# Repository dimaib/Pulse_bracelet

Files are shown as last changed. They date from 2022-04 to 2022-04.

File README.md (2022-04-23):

# Oxemetry and pulsometry
## Description
This system allows you to distribute people between warehouse equipment and give permission to control certain types of machines. It also allows you to take into account the working hours of employees and conduct convenient analytics according to these hours.
## System Composition
- Wrist bracelet
	>The printed circuit board and circuit diagram of the device are created in [KiCad](https://www.kicad.org) 
	Firmware created in Keil uVision for ARM in C languages
- Server that receives data from devices and adds this data to the database
	>The server part was created in Visual Studio C ++, as a console application
	MySQL was used as the database. And MySQL Workbench for administration

## Main view PCB
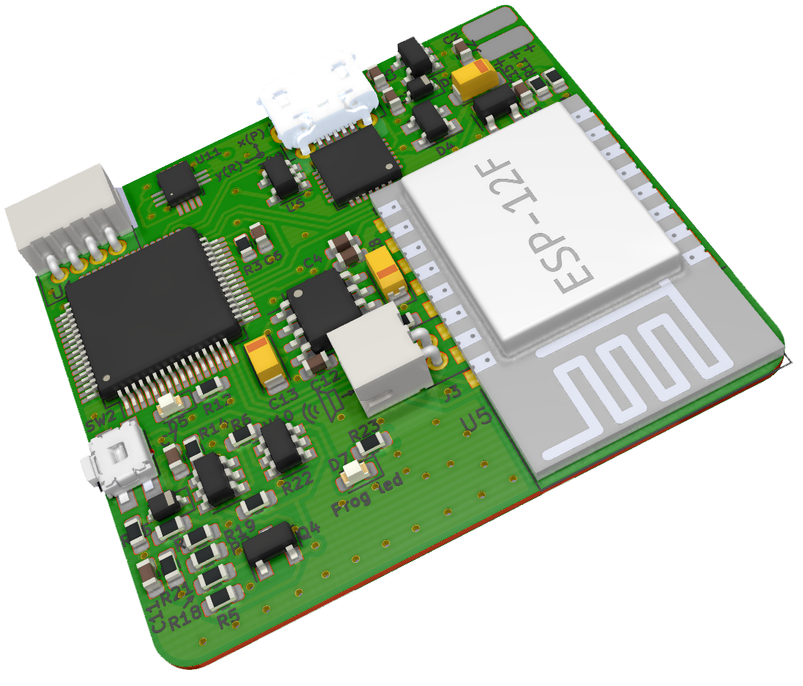
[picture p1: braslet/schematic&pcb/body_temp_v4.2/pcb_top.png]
PCB top

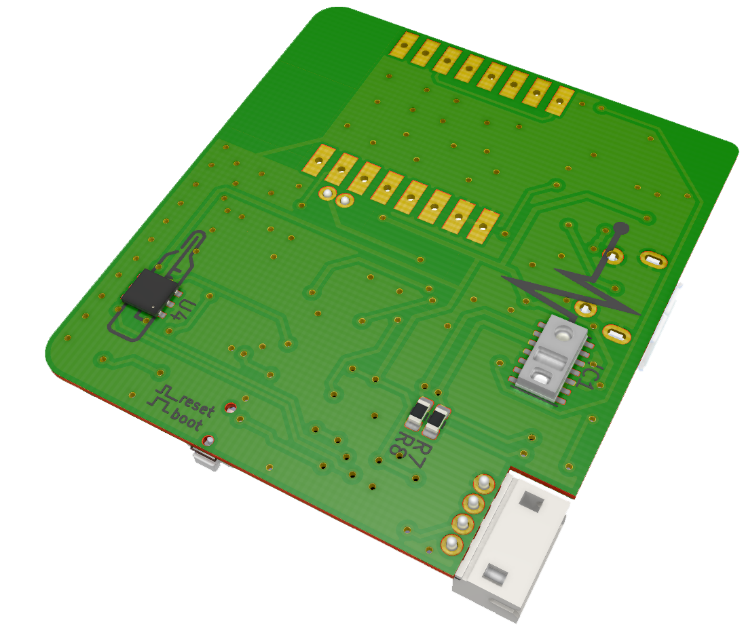
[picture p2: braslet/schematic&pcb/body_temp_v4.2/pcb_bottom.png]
PCB bottom


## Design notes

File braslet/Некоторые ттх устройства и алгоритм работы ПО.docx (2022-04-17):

Алгоритм работы ПО

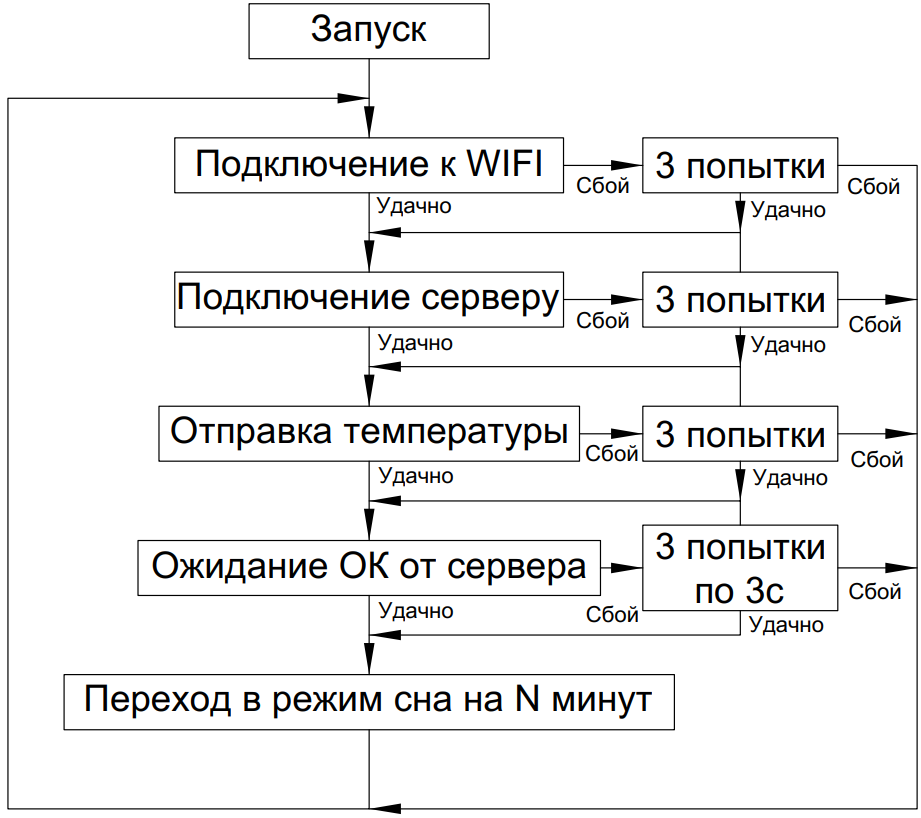
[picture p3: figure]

После запуска устройства происходит инициализация модуля WIFI и попытка подключения к точке доступа, если попытка не удалась, то устройство делает ещё 3 попытки, если они неудачны, то устройство уходит в сон на некоторое время. Если подключение прошло удачно, то устройство создаёт соединение с сервером по протоколу TCP\IP. Если с сервером не удалось соединиться 3 раза подряд, то программа переходит в режим сна. Если удалось создать соединение с сервером, устройство считывает 5 показаний датчика температуры и вычисляет из них среднее значение, после чего отправляет пакет данных на сервер и в течении 3 секунд ожидает ответа. Если ответа не последовало, то происходит ещё 3 попытки отправки пакета, если они не удачны, то устройство переходит в сон. Если попытка отправки пакета была удачной, то устройство переходит в сон.

Пакет отправки данных на сервер выглядит так:

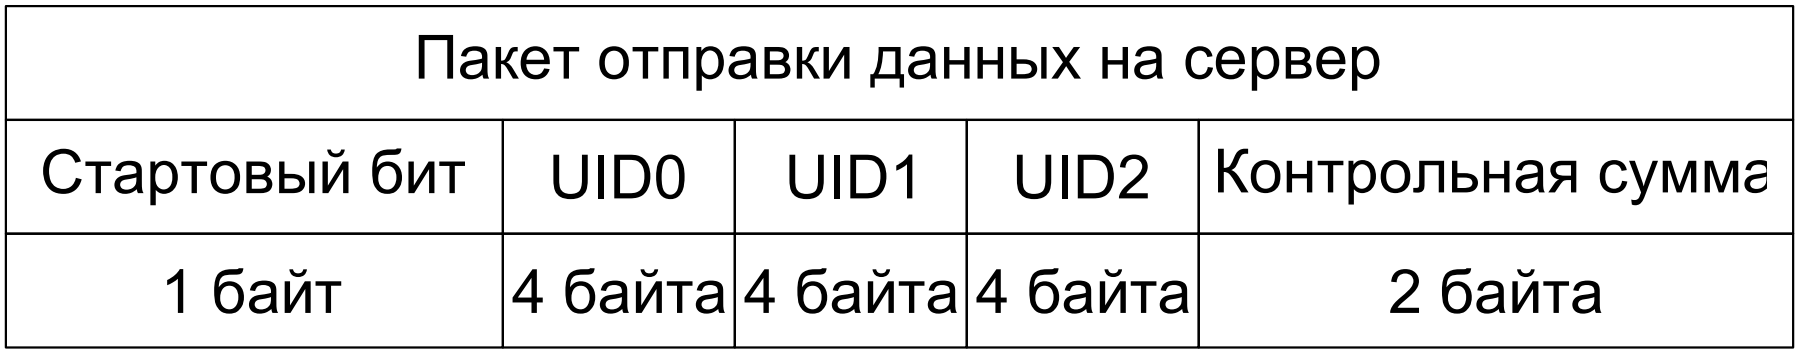
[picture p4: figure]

В режиме передачи данных и подключения к точке доступа WIFI устройство потребляет 80мА.

В режиме сна устройство потребляет не боле 150мкА.

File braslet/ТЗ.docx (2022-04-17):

Основные характеристики и моменты работы алгоритма устройства

Измерение температуры тела человека с помощью наручного браслета. Хранение результатов на сервере.

Интерфейс пользователя пока не требуется. Все данные смотрим и анализируем из базы данных, через MySQL Workbench (удобная визуализация и редактирование таблиц базы данных)

Храним измерения в течение 3х дней( чем больше тем лучше, но на данном этапе достаточно 3)

Температуру снимаем каждый час

Погрешность измерения температуры 0.1⁰

Если датчик будет внутри устройства, то для более точного измерения требуется осуществлять контакт с кожей через металлическую пластину

Если отсутствует wifi сигнал, записывать значения во внутреннюю память устройства

Устройство питается от Li-Pol аккумулятора 3.7В 300мАч

Предусмотреть зарядку Li-Pol аккумулятора от USB micro

Сервер работает на статическом IP-адресе.

Некоторые комплектующие:

Микроконтроллер STM32F070F6P6

WIFI модуль ESP-M3 или ESP-06

Аккумулятор Li-Pol 3.7В 300мАч размерами 30х30х3мм

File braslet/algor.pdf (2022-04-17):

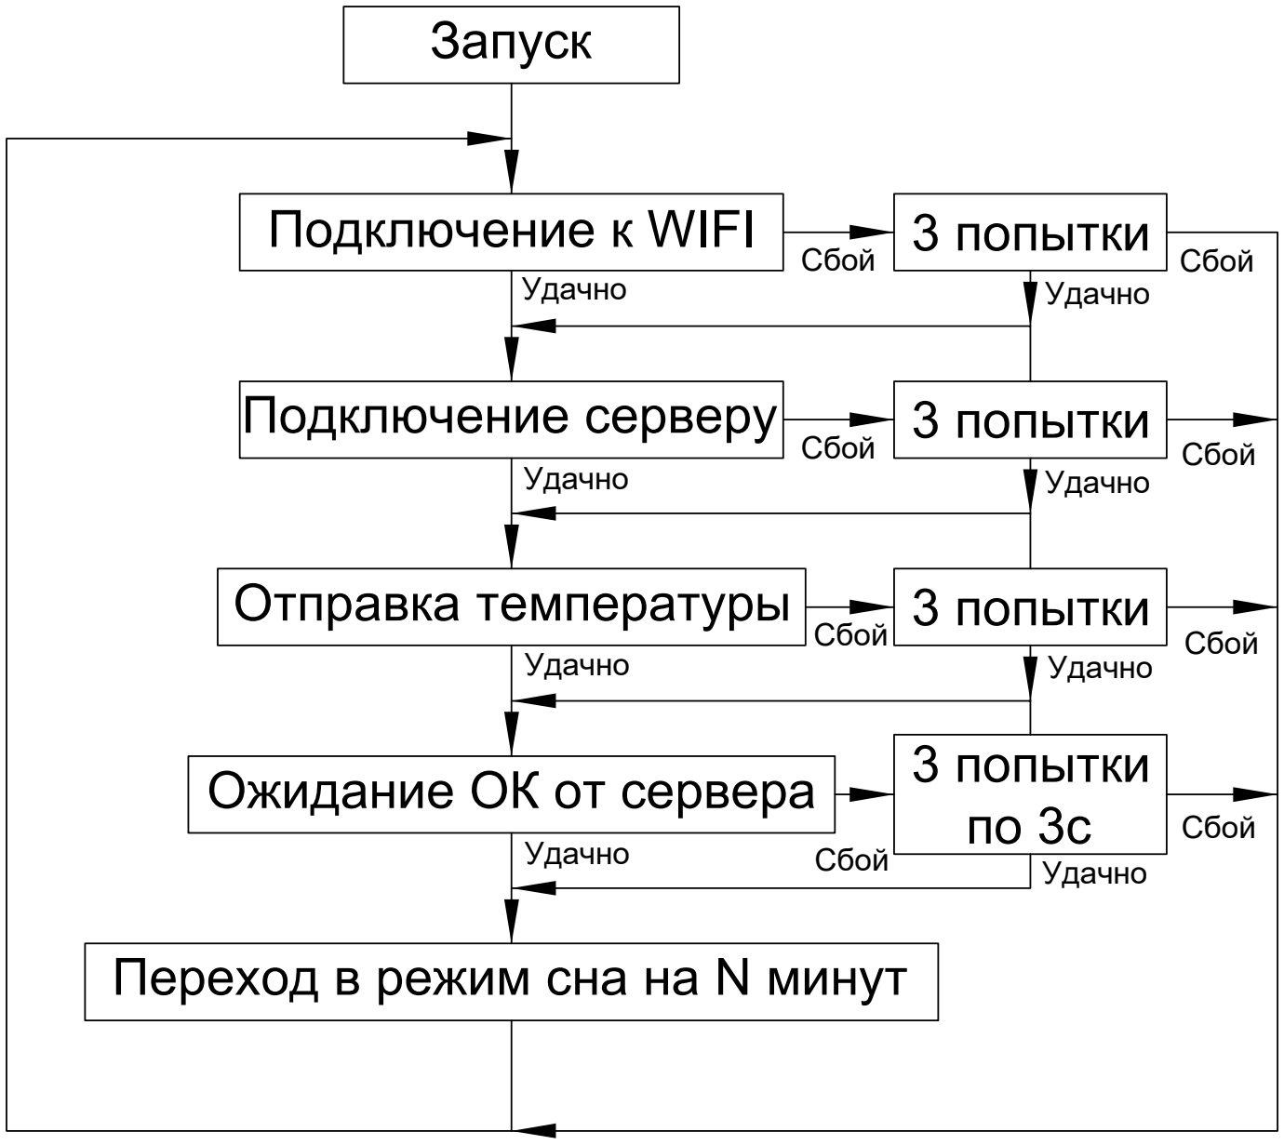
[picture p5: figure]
Запуск; Подключение к WIFI; Подключение серверу; Отправка температуры; Ожидание ОК от сервера; Переход в режим сна на N минут; 3 попытки; 3 попытки по 3с; Сбой; Удачно

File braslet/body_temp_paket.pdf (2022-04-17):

Стартовый бит | UID0 | UID1 | UID2 | Контрольная сумма
1 байт | 4 байта | 4 байта | 4 байта | 2 байта

Пакет отправки данных на сервер

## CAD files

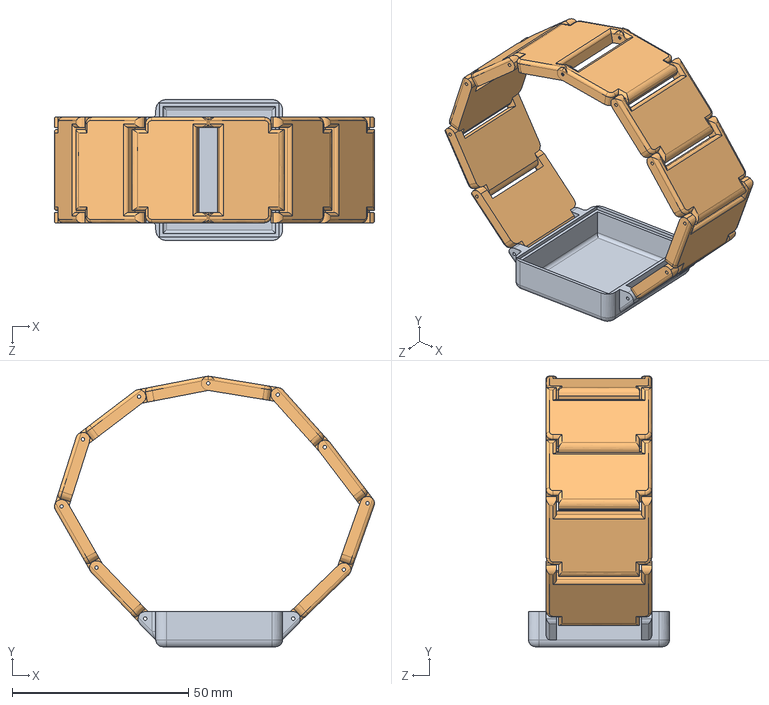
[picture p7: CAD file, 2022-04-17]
braslet/schematic&pcb/Корпуса/Корпус2/Сборка1.SLDASM
90.8 x 76.8 x 40.0 mm
Корпус
браслет x 10

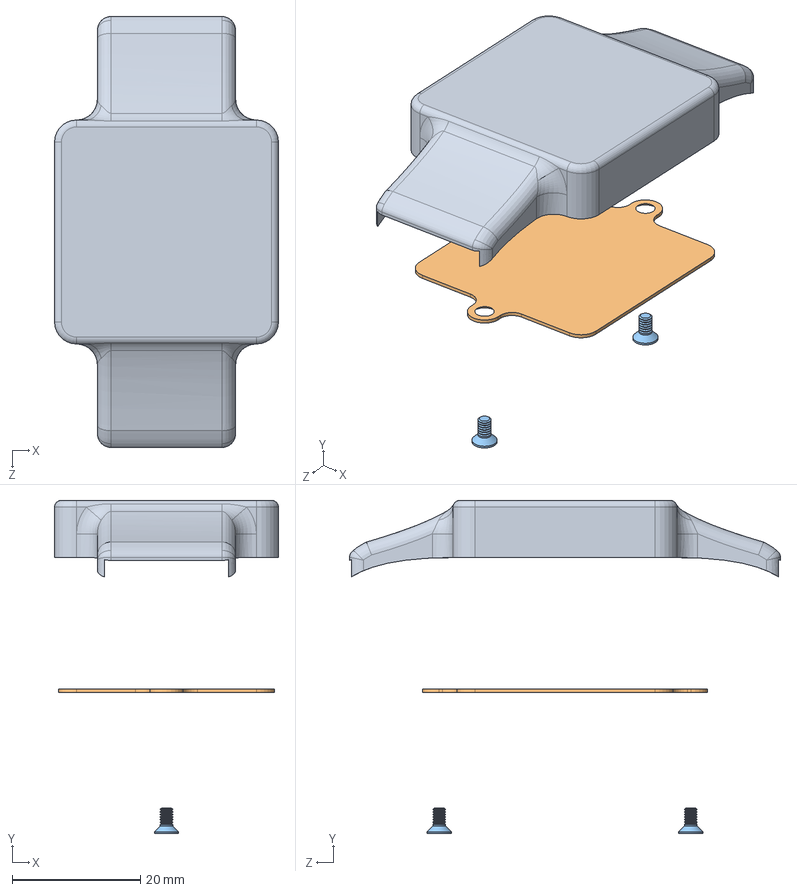
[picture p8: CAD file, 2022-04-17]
braslet/schematic&pcb/Корпуса/Корпус/Сборка1.SLDASM
35.0 x 52.1 x 67.3 mm
Корпус
Крышка
flat head screw_am x 2

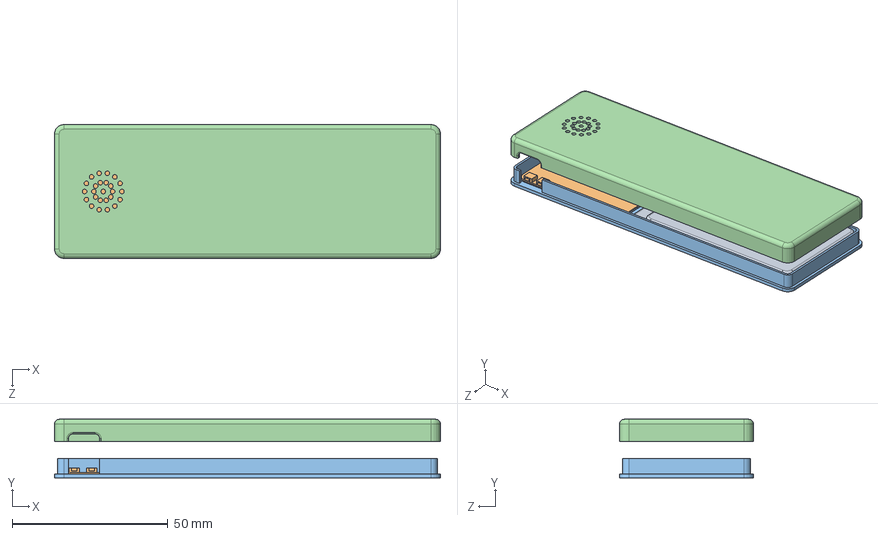
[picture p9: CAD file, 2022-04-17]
braslet/schematic&pcb/Корпуса/Корпус_103new/Сборка1.SLDASM
124.0 x 18.8 x 43.0 mm
аккумулятор
плата
Крышка
корпус

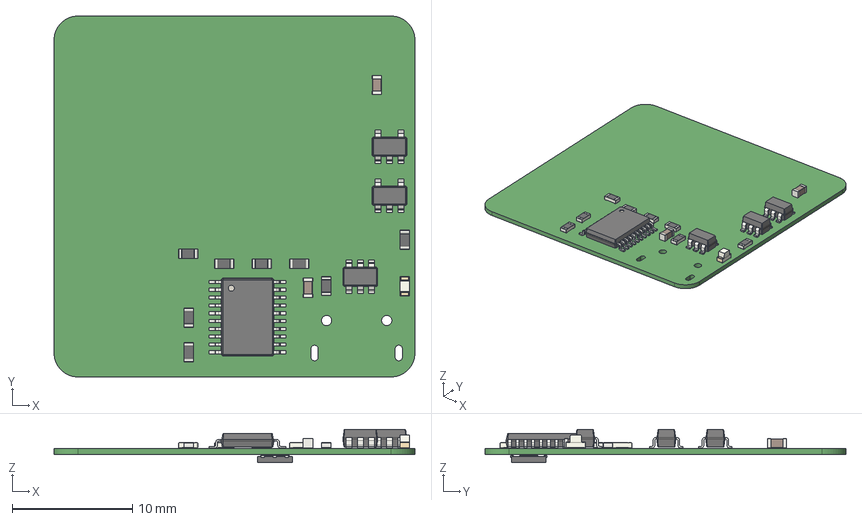
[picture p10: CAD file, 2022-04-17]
braslet/schematic&pcb/body_temp_103new/body_temp.step
30.0 x 30.0 x 2.75 mm
esp-12f_
crystal_05x3.2
usb_micro

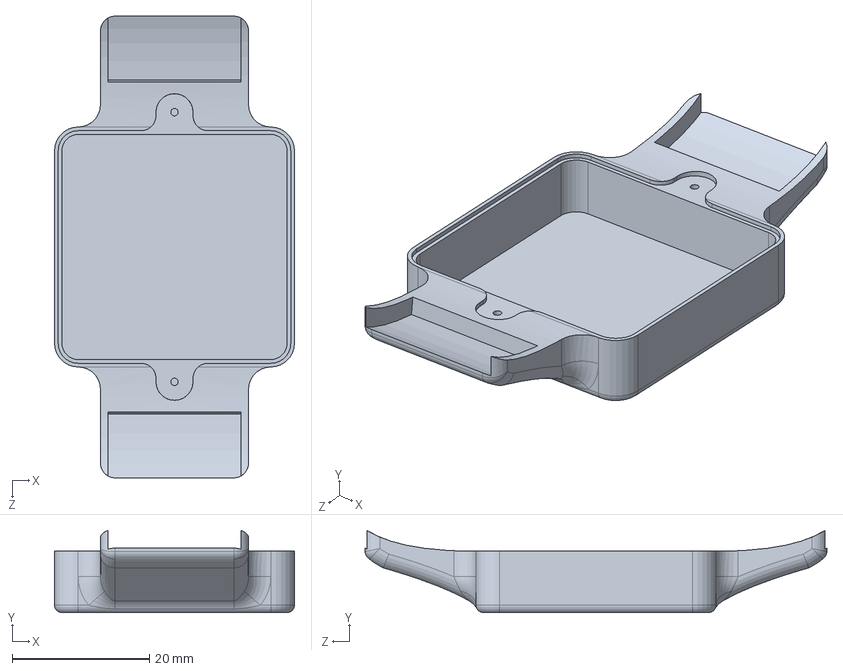
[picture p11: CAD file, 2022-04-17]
braslet/schematic&pcb/Корпуса/Корпус/Корпус.SLDPRT
35.0 x 12.0 x 67.3 mm

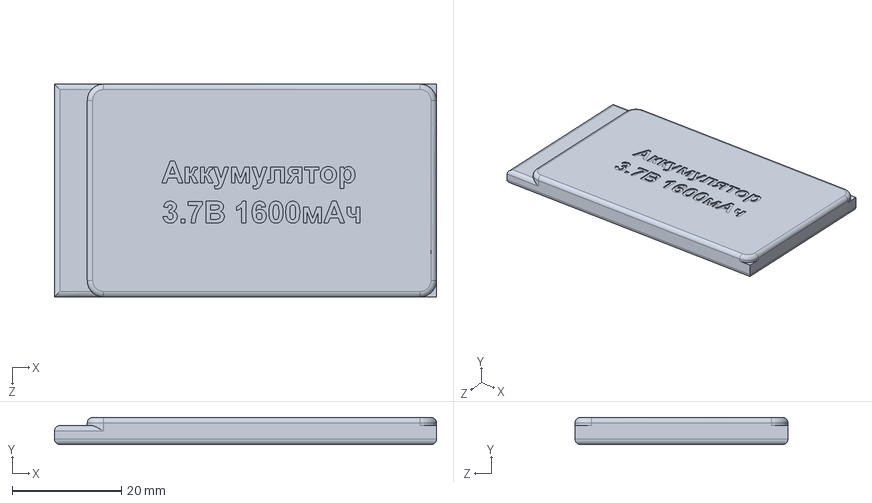
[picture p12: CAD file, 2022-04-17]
braslet/schematic&pcb/Корпуса/Корпус_103new/аккумулятор.SLDPRT
70.0 x 5.00 x 39.0 mm

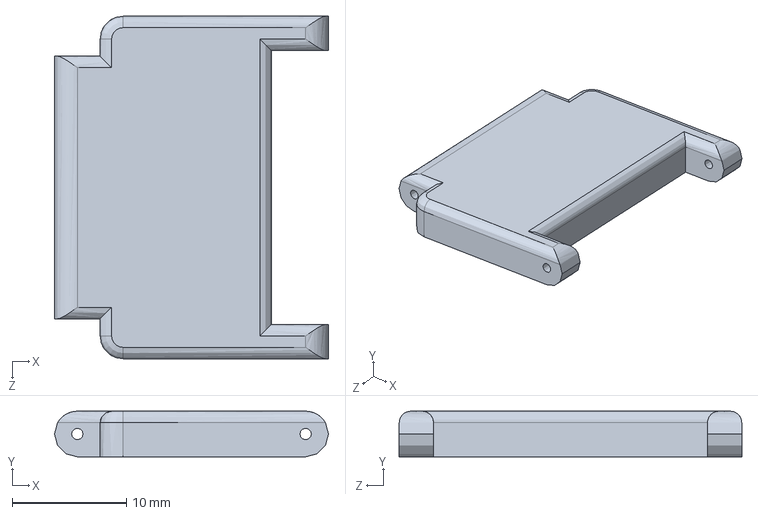
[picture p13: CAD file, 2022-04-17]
braslet/schematic&pcb/Корпуса/Корпус2/браслет.SLDPRT
24.0 x 4.00 x 30.0 mm

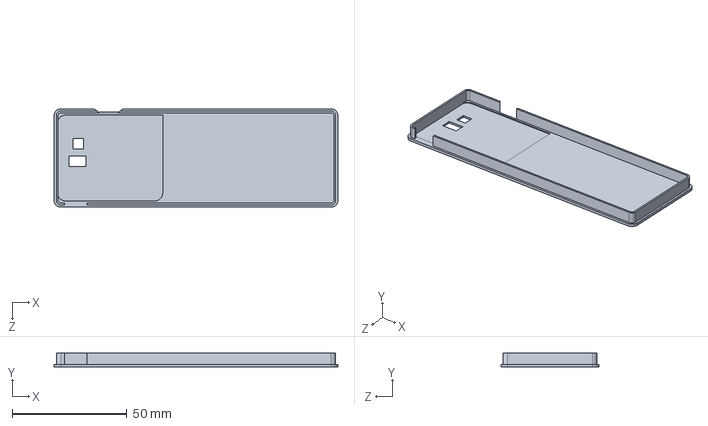
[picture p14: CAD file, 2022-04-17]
braslet/schematic&pcb/Корпуса/Корпус_103new/Крышка.SLDPRT
124.0 x 6.20 x 43.0 mm

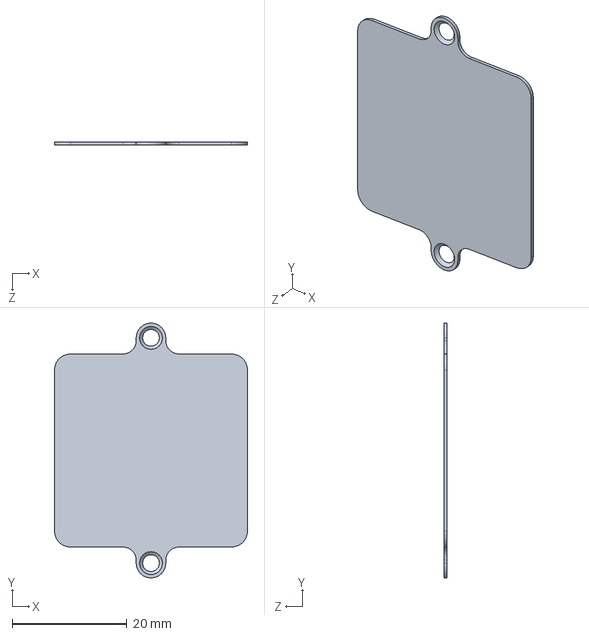
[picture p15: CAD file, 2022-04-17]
braslet/schematic&pcb/Корпуса/Корпус/Крышка.SLDPRT
33.7 x 44.5 x 0.54 mm

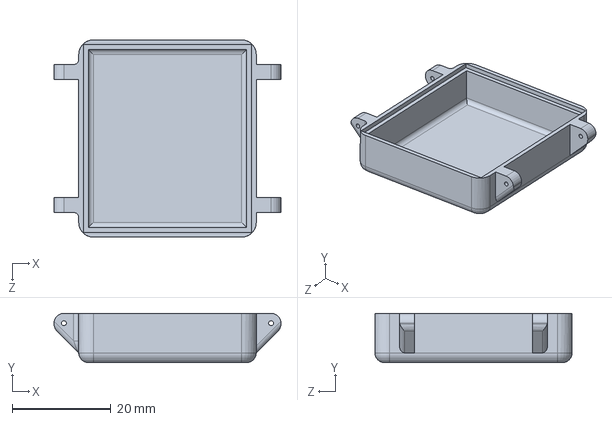
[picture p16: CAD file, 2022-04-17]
braslet/schematic&pcb/Корпуса/Корпус2/Корпус.SLDPRT
46.0 x 10.0 x 40.0 mm

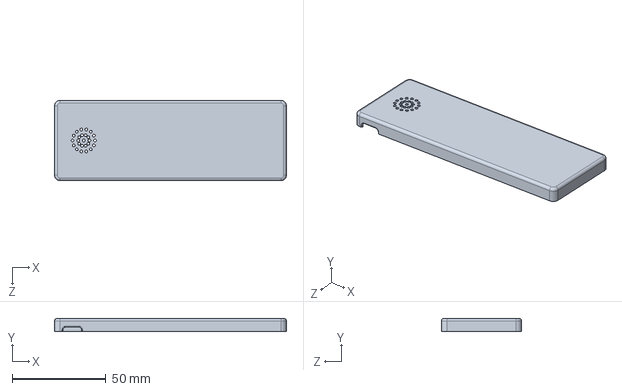
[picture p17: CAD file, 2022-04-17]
braslet/schematic&pcb/Корпуса/Корпус_103new/корпус.SLDPRT
124.0 x 7.20 x 43.0 mm

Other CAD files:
braslet/body_temp.dwg
braslet/schematic&pcb/body_temp_103new/body/esp-12f_.wrl.sldprt
braslet/schematic&pcb/body_temp_103new_fix/body/esp-12f_.wrl.sldprt
braslet/schematic&pcb/body_temp_103new_fix/esp-12f_.wrl.sldprt
braslet/schematic&pcb/body_temp_v4.2/body/esp-12f_.wrl.sldprt
braslet/schematic&pcb/body_temp_v4.2/esp-12f_.wrl.sldprt
braslet/schematic&pcb/body_temp_103new/esp-12f_.wrl.sldprt
braslet/schematic&pcb/body_temp_v3.1/body/esp-12f_.wrl.sldprt
braslet/schematic&pcb/body_temp_v3.1/esp-12f_.wrl.sldprt
braslet/schematic&pcb/old/body_temp/body/esp-12f_.wrl.sldprt
braslet/schematic&pcb/old/body_temp/esp-12f_.wrl.sldprt
braslet/schematic&pcb/old/body_temp_USB_update/body/esp-12f_.wrl.sldprt
braslet/schematic&pcb/old/body_temp_USB_update/esp-12f_.wrl.sldprt
braslet/schematic&pcb/Корпуса/Корпус2/Корпус.STL
braslet/schematic&pcb/Корпуса/Корпус2/браслет.STL
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

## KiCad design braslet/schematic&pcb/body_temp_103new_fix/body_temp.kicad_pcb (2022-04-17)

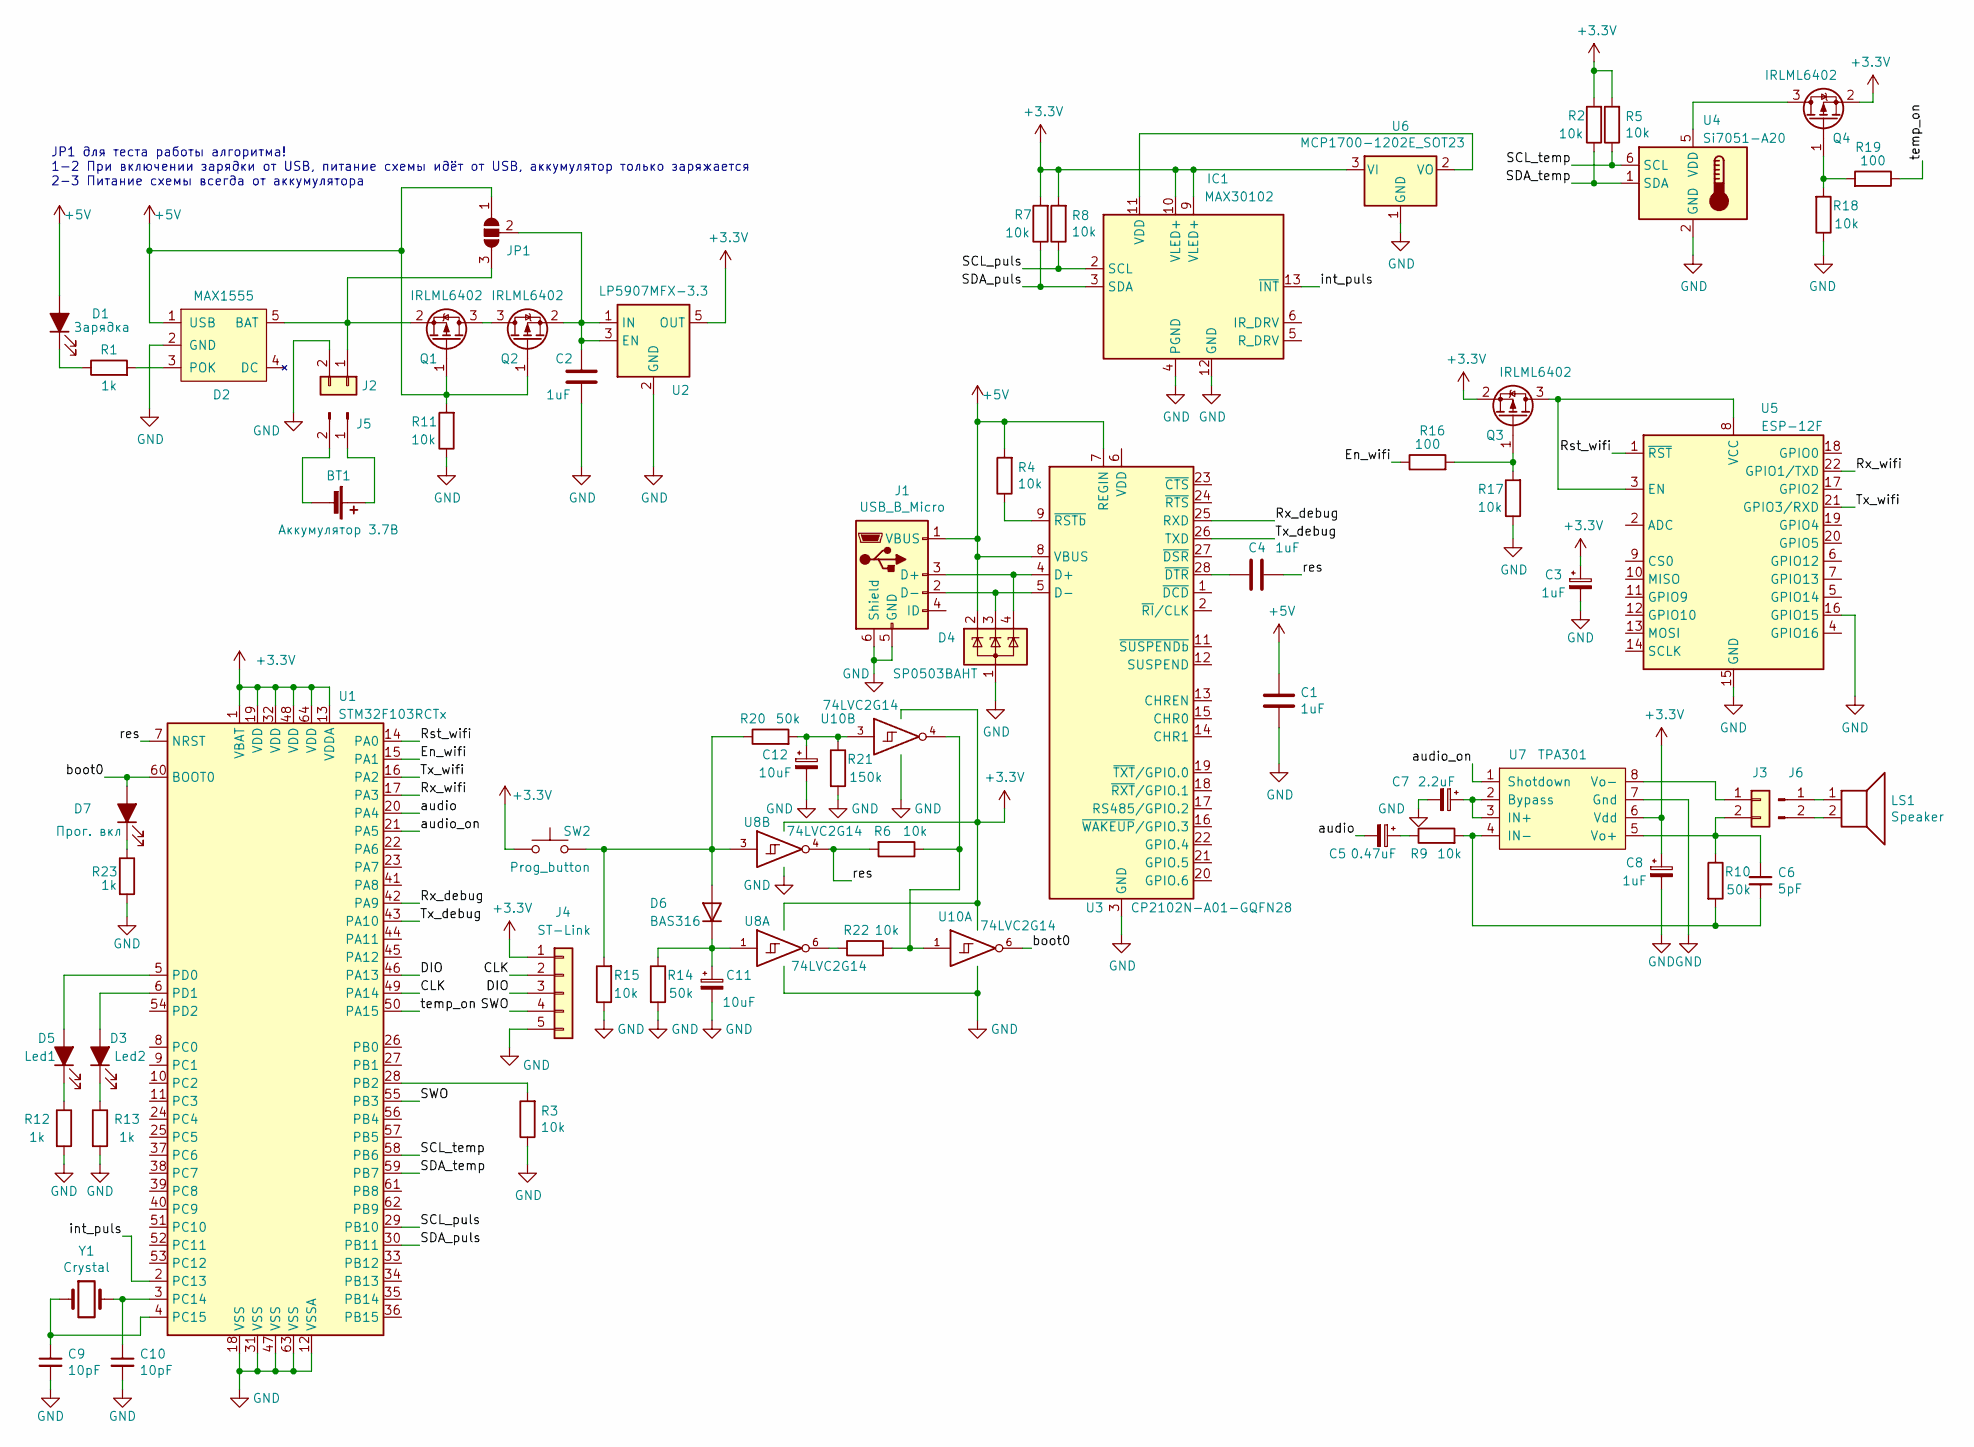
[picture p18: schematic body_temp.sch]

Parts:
BT1: Аккумулятор 3.7В
C1, C2, C4: 1uF; C_0603_1608Metric
C3, C8: 1uF; CP_EIA-3216-18_Kemet-A
C5: 0.47uF; CP_EIA-3216-18_Kemet-A
C6: 5pF; C_0603_1608Metric
C7: 2.2uF; CP_EIA-3216-18_Kemet-A
C9, C10: 10pF; C_0603_1608Metric
C11, C12: 10uF; CP_EIA-3216-18_Kemet-A
D1: Зарядка; LED_0603_1608Metric
D2: MAX1555; SOT-23-5
D3: Led2; LED_0603_1608Metric
D4: SP0503BAHT; SOT-143
D5: Led1; LED_0603_1608Metric
D6: BAS316; D_SOD-323
D7: Прог. вкл; LED_0603_1608Metric
IC1: MAX30102; Maxim_OLGA-14_3.3x5.6mm_P0.8mm
J1: USB_B_Micro; USB_Micro-B_Molex-105017-0001
J2: Аккумулятор на плату; ZH_Conn_02x01
J3: Динамик на плату; ZH_Conn_02x01
J4: ST-Link; ds1066-05m_2.0mm
J5: Аккумулятор на кабель
J6: Динамик на кабель
JP1: SolderJumper_3_Open; SolderJumper-3_P1.3mm_Open_RoundedPad1.0x1.5mm
LS1: Speaker
Q1, Q2, Q3, Q4: IRLML6402; SOT-23
R1, R12, R13, R23: 1k; R_0603_1608Metric
R2, R3, R4, R5, R6, R7, R8, R9, R11, R15, R17, R18, R22: 10k; R_0603_1608Metric
R10, R14, R20: 50k; R_0603_1608Metric
R16, R19: 100; R_0603_1608Metric
R21: 150k; R_0603_1608Metric
SW2: Prog_button; SW_SPST_EVQP7C
U1: STM32F103RCTx; LQFP-64_10x10mm_P0.5mm
U2: LP5907MFX-3.3; SOT-23-5
U3: CP2102N-A01-GQFN28; QFN-28-1EP_5x5mm_P0.5mm_EP3.35x3.35mm
U4: Si7051-A20; DFN-6-1EP_3x3mm_P1mm_EP1.5x2.4mm
U5: ESP-12F; ESP-12E
U6: MCP1700-1202E_SOT23; SOT-23
U7: TPA301; MSOP-8-1EP_3x3mm_P0.65mm_EP1.95x2.15mm
U8, U10: 74LVC2G14; SOT-23-6
Y1: Crystal; Crystal_SMD_G8-2Pin_3.2x1.5mm

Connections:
+3V3: C3.1, C8.1, IC1.9 (VLED+), IC1.10 (VLED+), J4.1, Q3.2 (S), Q4.2 (S), R2.2, R5.2, R7.2, R8.2, SW2.1, U1.1 (VBAT), U1.13 (VDDA), U1.19 (VDD), U1.32 (VDD), U1.48 (VDD), U1.64 (VDD), U2.5 (OUT), U6.3 (VI), U7.6 (Vdd), U8.5 (VCC), U10.5 (VCC)
+5V: C1.1, D1.2 (A), D2.1 (USB), D4.2 (K), J1.1 (VBUS), JP1.1 (A), Q1.1 (G), Q2.1 (G), R4.2, R11.2, U3.7 (REGIN), U3.8 (VBUS)
/CLK: J4.2, U1.49 (PA14)
/DIO: J4.3, U1.46 (PA13)
/En_wifi: R16.1, U1.15 (PA1)
/Rst_wifi: U1.14 (PA0), U5.1 (~RST)
/Rx_debug: U1.42 (PA9), U3.25 (RXD)
/Rx_wifi: U1.17 (PA3), U5.22 (GPIO1/TXD)
/SCL_puls: IC1.2 (SCL), R8.1, U1.29 (PB10)
/SCL_temp: R5.1, U1.58 (PB6), U4.6 (SCL)
/SDA_puls: IC1.3 (SDA), R7.1, U1.30 (PB11)
/SDA_temp: R2.1, U1.59 (PB7), U4.1 (SDA)
/SWO: J4.4, U1.55 (PB3)
/Tx_debug: U1.43 (PA10), U3.26 (TXD)
/Tx_wifi: U1.16 (PA2), U5.21 (GPIO3/RXD)
/audio: C5.2, U1.20 (PA4)
/audio_on: U1.21 (PA5), U7.1 (Shotdown)
/boot0: D7.2 (A), U1.60 (BOOT0), U10.6
/int_puls: IC1.13 (~INT), U1.2 (PC13)
/res: C4.1, R6.2, U1.7 (NRST), U8.4
/temp_on: R19.1, U1.50 (PA15)
GND: C1.2, C2.2, C3.2, C7.2, C8.2, C9.2, C10.2, C11.2, C12.2, D2.2 (GND), D4.1 (A), IC1.4 (PGND), IC1.12 (GND), J1.5 (GND), J1.6 (Shield), J2.2, J4.5, R3.1, R11.1, R12.2, R13.2, R14.2, R15.1, R17.1, R18.1, R21.2, R23.2, U1.12 (VSSA), U1.18 (VSS), U1.31 (VSS), U1.47 (VSS), U1.63 (VSS), U2.2 (GND), U3.3 (GND), U3.29 (GND), U4.2 (GND), U5.15 (GND), U5.16 (GPIO15), U6.1 (GND), U7.7 (Gnd), U8.2 (GND), U10.2 (GND)
unnamed: BT1.1 (+), J5.1
unnamed: BT1.2 (-), J5.2
unnamed: C2.1, JP1.2 (C), Q2.2 (S), U2.1 (IN), U2.3 (EN)
unnamed: C4.2, U3.28 (~DTR)
unnamed: C5.1, R9.1
unnamed: C6.1, J3.2, R10.1, U7.5 (Vo+)
unnamed: C6.2, R9.2, R10.2, U7.4 (IN-)
unnamed: C7.1, U7.2 (Bypass), U7.3 (IN+)
unnamed: C9.1, U1.4 (PC15), Y1.1
unnamed: C10.1, U1.3 (PC14), Y1.2
unnamed: C11.1, D6.1 (K), R14.1, U8.1
unnamed: C12.1, R20.2, R21.1, U10.3
unnamed: D1.1 (K), R1.1
unnamed: D2.3 (POK), R1.2
unnamed: D2.5 (BAT), J2.1, JP1.3 (B), Q1.2 (S)
unnamed: D3.1 (K), R13.1
unnamed: D3.2 (A), U1.6 (PD1)
unnamed: D4.3 (K), J1.2 (D-), U3.5 (D-)
unnamed: D4.4 (K), J1.3 (D+), U3.4 (D+)
unnamed: D5.1 (K), R12.1
unnamed: D5.2 (A), U1.5 (PD0)
unnamed: D6.2 (A), R15.2, R20.1, SW2.2, U8.3
unnamed: D7.1 (K), R23.1
unnamed: IC1.11 (VDD), U6.2 (VO)
unnamed: J3.1, U7.8 (Vo-)
unnamed: J6.1, LS1.1
unnamed: J6.2, LS1.2
unnamed: Q1.3 (D), Q2.3 (D)
unnamed: Q3.1 (G), R16.2, R17.2
unnamed: Q3.3 (D), U5.3 (EN), U5.8 (VCC)
unnamed: Q4.1 (G), R18.2, R19.2
unnamed: Q4.3 (D), U4.5 (VDD)
unnamed: R3.2, U1.28 (PB2)
unnamed: R4.1, U3.9 (~RSTb)
unnamed: R22.1, U8.6
unnamed: R6.1, R22.2, U10.1, U10.4

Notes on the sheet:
JP1 для теста работы алгоритма! 1-2 При включении зарядки от USB, питание схемы идёт от USB, аккумулятор только заряжается 2-3 Питание схемы всегда от аккумулятора

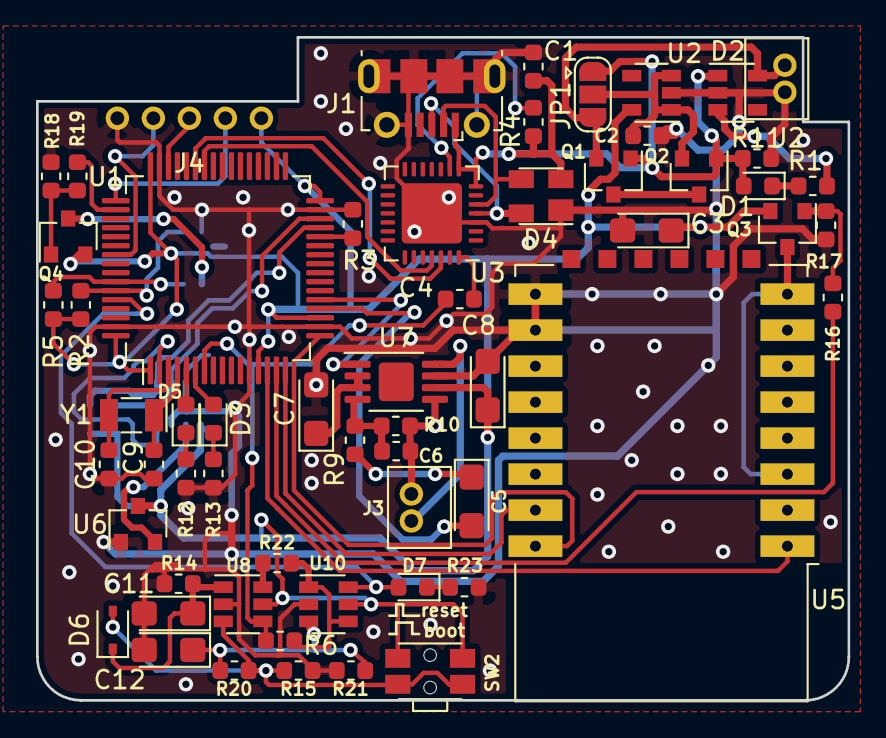
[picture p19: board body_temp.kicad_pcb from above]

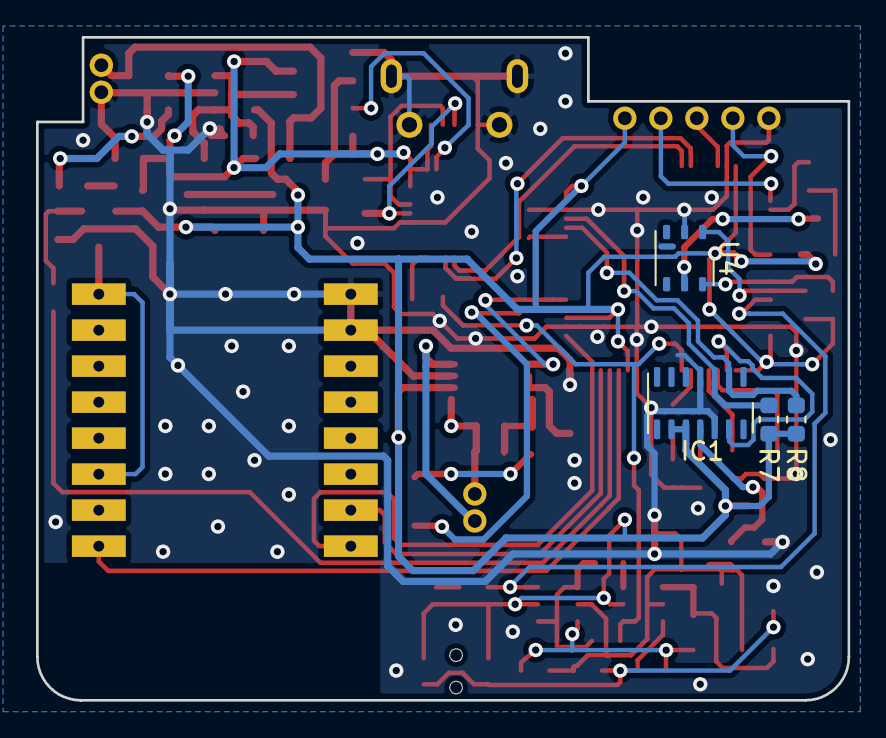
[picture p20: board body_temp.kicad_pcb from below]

Board: 2 copper layers, 45.1 x 36.8 mm, 63 parts (4 on the bottom side), 54 nets.

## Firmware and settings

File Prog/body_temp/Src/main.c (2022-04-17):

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

/* Includes ------------------------------------------------------------------*/
#include "main.h"
#include "i2c.h"
#include "rtc.h"
#include "usart.h"
#include "gpio.h"

/* USER CODE BEGIN Includes */
//#include "usbd_cdc_if.h"

#include <string.h>
#include "function.h"	
#include "Si7021_driver.h"
/* USER CODE END Includes */


void SystemClock_Config(void);
/* USER CODE BEGIN 0 */
//float temp_buf[BUFFER_TEMP_SIZE]={0.0};												//массив для хранения показаний температуры за сутки
/* USER CODE END 0 */

/**
  * @brief  The application entry point.
  * @retval int
  */
int main(void)
{
  /* MCU Configuration--------------------------------------------------------*/

  /* Reset of all peripherals, Initializes the Flash interface and the Systick. */
  HAL_Init();

  /* Configure the system clock */
  SystemClock_Config();

  /* Initialize all configured peripherals */
  MX_GPIO_Init();
  MX_USART2_UART_Init();
  MX_I2C1_Init();
  MX_USART1_UART_Init();
  MX_RTC_Init();
  /* USER CODE BEGIN 2 */

	USART2->CR1 = USART_CR1_UE;
	NVIC_EnableIRQ(USART2_IRQn); USART2->CR1 |= USART_CR1_TE | USART_CR1_RE | USART_CR1_RXNEIE;        //разрешение прерывания по приёму данных UART2
	WIFI_EN;
  /* USER CODE END 2 */

  /* Infinite loop */
  /* USER CODE BEGIN WHILE */
	HAL_Delay(200);
	debug((uint8_t*)"Start system\r\n",0);
	
	rst_Si7021();
	//uint16_t wait_send_server=0;
  while (1)
  {
		//debug_uid();
		commands();																											//обработка очереди команд в системном регистре флагов com_flags (16 бит)
		HAL_Delay(100);
    /* USER CODE END WHILE */

    /* USER CODE BEGIN 3 */
  }
  /* USER CODE END 3 */
}

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


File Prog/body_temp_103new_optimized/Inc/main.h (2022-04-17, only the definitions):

#define DEBUG_ON																																			//Включение\отключение вывода информации в дебаг
#define WIFI_RES			GPIOA->ODR&=~(1<<0); HAL_Delay(500)															//сброс WI-FI
#define WIFI_ON				GPIOA->ODR|=(1<<0); HAL_Delay(500)															//включение WI-FI
#define WIFI_DIS			GPIOA->ODR&=~(1<<1); HAL_Delay(200)															//запрет WI-FI
#define WIFI_EN				GPIOA->ODR|=(1<<1); HAL_Delay(400)															//разрешение WI-FI
#define BUFFER_MAX 				60 																													//размер буфера приёма. Не должно превышать uint16_t
#define BUFFER_SEND				40																													//размер буфера для отправки сообщений на сервер
#define DELAY_OK_SEND			500																													//таймаут ожидания ответа OK или '>'
#define BUFF2_NULL				for(uint16_t i=0;i<BUFFER_MAX;i++) buf_uart2[i]=NULL				//обнуление буффера приёма по UART2
#define STR_OK						"OK!\r\n"
#define STR_ERROR					"ERROR!\r\n"
#define STR_START_INIT		"WIFI setup - START\r\n***********************\r\n"
#define STR_END_INIT			"***********************\r\nWIFI setup - END\r\n"
#define STR_WIFI_CON			"Connect WIFI\r\n"
#define STR_SET_IP				"IP addres OK!\r\n"
#define STR_BUILD_TCP			"Creating a TCP to the server\r\n"
#define STR_TCP_ERROR			"Creating TCP to the server ERROR\r\n"
#define STR_TCP_OK				"Creating TCP to the server OK\r\n"
#define STR_BUF_OVER1			"Buffer is overloaded. Stop recive..\r\n"
#define STR_BUF_OVER			""
#define CLIENT_OK					"t_ok\r\n"																			//ответаная строка от сервера об успешном приёме данных
#define ATE0  				(uint8_t*)"ATE0\r\n" 																						//отключить эхо
#define CWMODE 				(uint8_t*)"AT+CWMODE=1\r\n"																			//..
#define CIPMODE 			(uint8_t*)"AT+CIPMODE=0\r\n"																		//..
#define CIPMUX 				(uint8_t*)"AT+CIPMUX=0\r\n"																			//..
#define CWAUTOCONN 		(uint8_t*)"AT+CWAUTOCONN=0\r\n"																	//..
#define CONNECT_AP		(uint8_t*)"AT+CWJAP="																						//подключиться к точке доступа
#define GET_IP 				(uint8_t*)"AT+CIFSR\r\n"																				//узнать полученый IP адрес
#define BUILD_TCP 		(uint8_t*)"AT+CIPSTART=\"TCP\","																//установить TCP соединение
#define CLOSED_TCP 		(uint8_t*)"AT+CIPCLOSE\r\n"																			//разорвать TCP соединение
#define DISCON_AP			(uint8_t*)"AT+CWQAP\r\n"																				//отключиться от точки доступа
#define SEND_WIFI			(uint8_t*)"AT+CIPSEND="																					//отправить данные по TCP
#define WIFI_AP  			(uint8_t*)"dimaib"     																					//имя точки доступа
#define WIFI_PASS 		(uint8_t*)"23092309"   																					//пароль точки доступа
#define SERVER_ADDR		(uint8_t*)"192.168.31.184"																			//сетевой адрес сервера
#define SERVER_PORT		(uint8_t*)"7770"																								//сетевой порт сервера
#define WIFI_AP  			(uint8_t*)"Mi A3"     																					//имя точки доступа
#define WIFI_PASS 		(uint8_t*)"20119288"   																					//пароль точки доступа
#define SERVER_ADDR		(uint8_t*)"192.168.43.200"																			//сетевой адрес сервера
#define SERVER_PORT		(uint8_t*)"7770"																								//сетевой порт сервера
#define WIFI_AP  			(uint8_t*)"ISL-Technopark"     																	//имя точки доступа
#define WIFI_PASS 		(uint8_t*)"ISLwifi2019"   																			//пароль точки доступа
#define SERVER_ADDR		(uint8_t*)"192.168.43.200"																			//сетевой адрес сервера
#define SERVER_PORT		(uint8_t*)"7770"																								//сетевой порт сервера
#define WIFI_AP  			(uint8_t*)"this is sparta"     																	//имя точки доступа
#define WIFI_PASS 		(uint8_t*)"23092309"   																					//пароль точки доступа
#define SERVER_ADDR		(uint8_t*)"192.168.43.109"																			  //сетевой адрес сервера
#define SERVER_PORT		(uint8_t*)"7770"	
#define WIFI_AP  			(uint8_t*)"Honor8990896789"     																//имя точки доступа
#define WIFI_PASS 		(uint8_t*)"4422wwqq"   																					//пароль точки доступа
#define SERVER_ADDR		(uint8_t*)"192.168.43.109"																			//сетевой адрес сервера
#define SERVER_PORT		(uint8_t*)"7770"	
#define START_BYTE			0xAA																													//стартовый байт при передачи по wifi 10101010
#define BUF_SEND_SIZE 	26																														//размер посылки серверу
#define MAX_WIFI_ERROR	3																															//максимальное кол-во неудачных попыток подключения к точке доступа, после чего требуется перезагрузить WIFI
#define MAX_TCP_ERROR		10																														//максимальное кол-во неудачных попыток подключения к серверу, после чего требуется перезагрузить WIFI
#define MAX_TIME_WDT		3000																													//максимальное время молчания или бездействия сервера
#define MAX_TCP_DELAY		3000																													//максимальное время ожидания между неудачными подключениями TCP в мс. SysTick
#define WIFI_DISC			"WIFI DISCONNECT"																								//при успешном получении IP-адреса
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

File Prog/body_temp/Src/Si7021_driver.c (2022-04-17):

#include <Si7021_driver.h>
#include <i2c.h>

static const uint16_t I2C_ADDR = (0x40<<1);           // Si7021 I2C address

static uint8_t user_register_1 = 0x3A;

static float process_temp_code(uint16_t temp_code);
static uint16_t convert_to_uint16(uint8_t bytes[]);
//static int8_t w_reg(uint8_t value, Si7021_registers_t reg);
static int8_t r_reg(Si7021_registers_t reg);

static float process_temp_code(uint16_t temp_code)
{
  return (float)(((175.72 * temp_code) / 65536.0) - 46.85);
}

static uint16_t convert_to_uint16(uint8_t bytes[])
{
  return (uint16_t)((bytes[0]<<8) | bytes[1]);
}

static int8_t r_reg(Si7021_registers_t reg)
{
  uint8_t cmd;
  uint8_t* data;

  if(reg == User_Register_1)
  {
    cmd = R_RHT_U_reg;
    data = &(user_register_1);
  }
  else
    return -1;

  if(HAL_OK != HAL_I2C_Mem_Read(&hi2c1, I2C_ADDR, cmd, 1, data, 1, 10000))
    return -1;
  else
    return 0;
}
/*
static int8_t w_reg(uint8_t value, Si7021_registers_t reg)
{
  uint16_t cmd;

  if(reg == User_Register_1)
  {
    cmd = W_RHT_U_reg;
  }
  else if(reg == Heater_Control_Register)
  {
    cmd = W_Heater_C_reg;
  }
  else
    return -1;

  if(HAL_OK != HAL_I2C_Mem_Write(&hi2c1, I2C_ADDR, cmd, 1, &value, 1, 10000))
    return -1;
  else
    return 0;
}
*/

float r_single_Si7021()
{
  uint8_t cmd;
  uint8_t buffer[2];
  uint16_t code;

  cmd = Temp_HM;

  if(HAL_OK != HAL_I2C_Master_Transmit(&hi2c1, I2C_ADDR, &cmd, 1, 10000))
    return -1.0f;

  if(HAL_OK != HAL_I2C_Master_Receive(&hi2c1, I2C_ADDR, buffer, 2, 10000))
    return -1.0f;

  code = convert_to_uint16(buffer);
  return process_temp_code(code);
}

int8_t r_firmware_rev_Si7021()
{
  uint16_t cmd = (R_Firm_rev2<<8) | R_Firm_rev1;
  uint8_t data;

  if(HAL_OK != HAL_I2C_Master_Transmit(&hi2c1, I2C_ADDR, (uint8_t*)(&cmd), 2, 10000))
    return -1;

  if(HAL_OK != HAL_I2C_Master_Receive(&hi2c1, I2C_ADDR, &data, 1, 10000))
    return -1;

  switch(data)
  {
    case 0xFF: return 1;
    case 0x20: return 2;
    default: return -1;
  }
}

int8_t rst_Si7021()
{
  uint8_t cmd = Si7021_Reset;

  if(HAL_OK != HAL_I2C_Master_Transmit(&hi2c1, I2C_ADDR, &cmd, 1, 10000))
    return -1;
  else
    return 0;
}

int8_t get_register(Si7021_registers_t reg, uint8_t* rv)
{
  if(r_reg(reg) < 0)
    return -1;

  if(reg == User_Register_1)
    *rv = user_register_1;

  return 0;
}

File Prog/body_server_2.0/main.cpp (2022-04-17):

#include <iostream>
#include <sstream>
#include <string>
#include <stdio.h>
#include <thread>
#include <WinSock2.h>
#include <WS2tcpip.h>
#include <mutex>
#include <ctime>

/*пользовательские заголовки*/
//#include <mysql.h>																	//файл с API mysql баз данных
#include "database.h"																	//файл с функциями для работы с базой данных
#include "function.h"																	//файл со служебными функциями
#include "thread_function.h"															//файл с подпрограммами потоков
/*пользовательские заголовки*/

#include "main.h"

#pragma comment(lib, "Ws2_32.lib")														//Необходимо, чтобы линковка происходила с DLL-библиотекой. Для работы с сокетам

//#define _WINSOCK_DEPRECATED_NO_WARNINGS

using namespace std;

/////////////////////////////////////////////////////////////////////////////////////////


int main()
{
	setlocale(LC_CTYPE, "russian");														//для правильного вывода ресского текста в консоль
	system("title Сервер обработки body temp");											//установить заголовок окна
	if (!database_init()) {																//если база данных не инициализирована
		printf("Ошибка инициализации базы данных!\r\n"); 
		system("pause");  
		return 0; 
	} else {
		printf("База данных успешно инициализирована!\r\n");
		mysql_close(conn);
	}

	if (socket_init()) {																//инициализация сетевого протокола
		printf("Ошибка инициализации сетевого протокола, программа будет завершена!\r\n");
		return 1;
	}
																
	thread func_thread(wotch_dog);														//создание потока сторожевого таймера
	func_thread.detach();																//отсоединение потока от функции
	thread func_synhro(synhro_application);												//создание потока синхронизации открытых соединений с устройством
	func_synhro.detach();																//отсоединение потока от функции


	char buf[100] = {0};																//буффер ответа клиенту на запрос подключения
	printf("Сервер запущен!\r\n");
	char buf_send[32];	

	for (;; Sleep(75)) {
		if (Connect = accept(Listen, NULL, NULL)) {										//одобрение входящего подключения
			mut.lock();																	//блокировка потока
			ClientCount++;																//прибавляем кол-во клиентов
			printf("Пользователь подключен #%d\t\t\t-=%d=-\r\n", buf_user_id[0], ClientCount);
			application[buf_user_id[0]].Connections = Connect;							//ID подключения
			application[buf_user_id[0]].buf_wdt_user = clock();							//время создания подключения, для сторожевого таймера
			sprintf_s(buf_send,"con_ok\r\n");
			send(application[buf_user_id[0]].Connections, buf_send,(int)strlen(buf_send),NULL);	//ответ клиенту об удачном подключении
			thread func_thread(SendMessageToClient, buf_user_id[0]);					//создание потока нового клиента
			func_thread.detach();														//отсоединение потока от функции
			for (int i = 0; i < BUF_USER_SIZE; i++) {									//обработка очереди подключений
				if (buf_user[i] == -1) { buf_user[i] = buf_user_id[0]; break; }			//поиск свободной позиции в массиве и помещаем туда номер подключения
			}
			for (int i = 0; i < BUF_USER_SIZE - 1; i++) buf_user_id[i] = buf_user_id[i + 1];//удаление нулевого элемента и смещение очереди влево 
			buf_user_id[BUF_USER_SIZE - 1] = -1;
			debug_connect_buffer(DEBUG_CON_INFO);										//вывод отладочной информации об очереди и буферах подключений
			mut.unlock();																//разблокировка потока
		}
	}
	return 0;
}

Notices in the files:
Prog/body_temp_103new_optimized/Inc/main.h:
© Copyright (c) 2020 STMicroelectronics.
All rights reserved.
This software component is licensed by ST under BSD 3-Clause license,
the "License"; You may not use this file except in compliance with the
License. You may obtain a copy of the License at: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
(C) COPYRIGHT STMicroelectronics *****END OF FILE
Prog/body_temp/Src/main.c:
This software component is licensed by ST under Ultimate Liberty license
